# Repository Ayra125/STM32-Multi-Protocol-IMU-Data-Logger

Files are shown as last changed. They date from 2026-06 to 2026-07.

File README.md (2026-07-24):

# STM32 Multi-Protocol IMU Data Logger

A custom two-layer STM32F446 PCB and firmware architecture for a multi-protocol IMU data logger —
designed to sample an IMU over I²C, log to SPI flash, drive an OLED, and stream telemetry through a
USB-UART bridge. The board was designed from first principles in Altium and taken through schematic,
layout, DRC, and a full manufacturing (Gerber/BOM/CPL) review.

> **Project status — hardware-design & firmware-architecture prototype.** Revision 1 of the PCB is
> design-complete and manufacturing-ready (ERC/DRC passed; Gerber/drill/BOM/CPL generated and reviewed
> for JLCPCB), and the three peripheral drivers plus the end-to-end data-logging loop are written. The
> firmware **builds clean** (zero warnings) and has been **flashed to a Nucleo-F446RE**, where the main
> loop, USART2 telemetry (115200), and error-handling paths are confirmed running. However, the custom
> board has **not** been fabricated or electrically tested, and the sensor/OLED/flash **success paths
> have not yet been validated with the peripherals wired up**. Treat this as a PCB + firmware-
> architecture prototype, not a fully validated data logger — see
> [Known limitations](#known-limitations--revision-2).

The point of the project is to demonstrate the electrical-level work a breakout module hides —
component selection, bus loading, pull-up sizing, decoupling, power, PCB layout, and design-rule
verification — not just firmware running on a dev board.

## Board preview

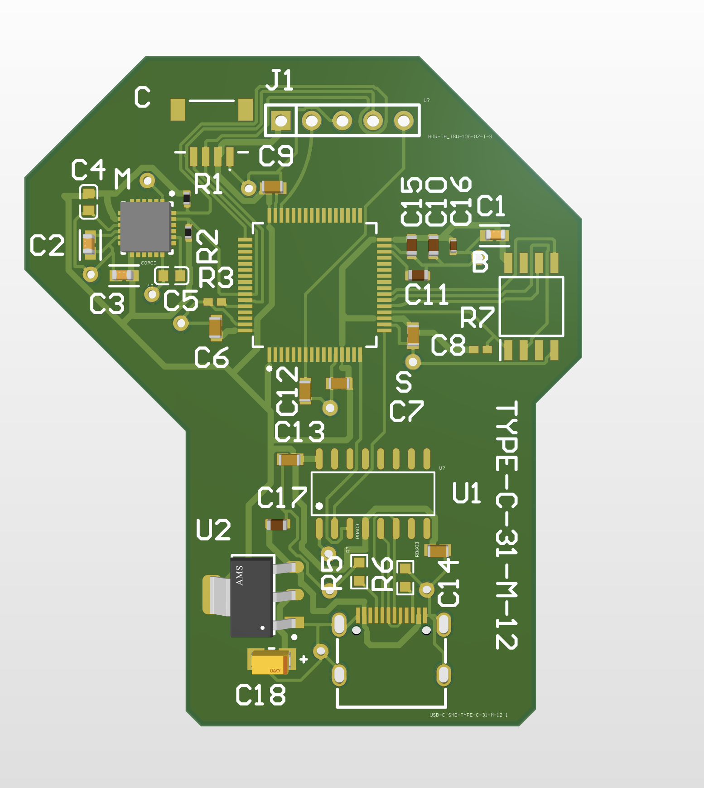
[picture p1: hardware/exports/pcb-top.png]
Altium 3D render of the Revision 1 board, top side


*Altium 3D render — top side, Revision 1.*

<!-- TODO after Altium export: hardware/exports/pcb-bottom.png + a clean schematic-only PDF -->
<!-- TODO after fabrication: assembled-board photo + a 20–40s demo GIF (IMU motion -> live OLED
     values -> UART telemetry in a terminal -> logged samples read back from flash) -->

## System architecture

```mermaid
graph LR
    USBC["USB-C<br/>(TYPE-C-31-M-12)"]
    LDO["AMS1117-3.3<br/>LDO"]
    CH340C["CH340C<br/>USB-UART bridge"]
    MCU["STM32F446RET6<br/>(LQFP-64)"]
    MPU["MPU-6050<br/>IMU"]
    OLED["SSD1306<br/>OLED (external)"]
    FLASH["W25Q128<br/>SPI flash"]

    USBC -->|"5 V"| LDO
    LDO -->|"3.3 V"| MCU
    USBC <-->|"USB D+/D-"| CH340C
    CH340C <-->|"USART2 (PA2/PA3)"| MCU
    MCU <-->|"I2C1 (PB6/PB7)"| MPU
    MCU <-->|"I2C1 (shared bus)"| OLED
    MCU <-->|"SPI1 (PA4-PA7)"| FLASH
```

- **I2C1** — the MCU reads the MPU-6050 IMU and drives the SSD1306 OLED: two devices sharing one bus
  (bus loading, shared pull-ups, address arbitration).
- **SPI1** — the MCU logs data to the W25Q128 flash: a different bus with a different electrical
  model (push-pull vs. I²C's open-drain).
- **USART2** — debug/telemetry to a host terminal, carried over USB-C via the CH340C bridge. USB is
  transport only (like an FTDI cable); USART2 stays the demonstrated protocol.

## What I personally designed

**Original design work (mine):**
- Full schematic (STM32 support/reset/boot, power tree, USB-C + CH340C, three-peripheral bus design).
- PCB layout, routing, ground pour, and design-rule setup for JLCPCB 2-layer manufacturing.
- All three peripheral drivers (`mpu6050`, `ssd1306`, `w25q128`) and the application data-logging loop in C.
- The engineering calculations below (pull-up sizing, bus capacitance, decoupling, LDO dissipation).

**CAD models — hand-built:** the USB-C receptacle symbol + footprint were drawn by hand, because no
usable vendor model existed for that part.

**CAD models — imported and then validated/adapted:** the CH340C and some capacitor models were
pulled in via EasyEDA/LCSC and then checked and adjusted for this design (pin mapping, land pattern,
parameters) rather than authored from scratch.

**Generated / vendor-provided (not my work):** STM32 HAL and CMSIS, and the CubeMX-generated
peripheral init / MSP boilerplate under `firmware/Core/` and `firmware/Drivers/`.

## Hardware specifications

| Function | Part | Bus / Role |
|---|---|---|
| MCU | STM32F446RET6 (LQFP-64) | — |
| IMU | MPU-6050 (QFN-24) | **I2C1** |
| OLED display | SSD1306 (external module, not on PCBA) | **I2C1** (shared bus) |
| Flash | W25Q128 (SOIC-8) | **SPI1** |
| USB-UART bridge | CH340C (SOP-16) | **USART2** telemetry to host |
| Connector | Single USB-C (TYPE-C-31-M-12) | Power-in + UART transport |
| Regulator | AMS1117-3.3 (SOT-223) | 5 V → 3.3 V |

- **Board:** 2-layer FR-4, 1.6 mm, 1 oz copper, ENIG finish, ≈ 46.1 mm × 55.37 mm.
- **Manufacturing:** JLCPCB SMT assembly (parts chosen JLCPCB-Basic where possible). The reviewed
  Revision 1 release lives in [`hardware/manufacturing/rev1/`](hardware/manufacturing/rev1).
- Firmware was developed on a Nucleo-F446RE; the custom board moves to the bare STM32F446RET6.

## Firmware architecture & data flow

Bare-metal STM32 HAL, no RTOS. Each peripheral is an independent driver module:

| Module | File | Bus |
|---|---|---|
| MPU-6050 IMU | `firmware/Peripherals/i2c/mpu6050.{c,h}` | I2C1 |
| SSD1306 OLED | `firmware/Peripherals/i2c/ssd1306.{c,h}` | I2C1 |
| W25Q128 flash | `firmware/Peripherals/spi/w25q128.{c,h}` | SPI1 |

`main()` configures the clock and peripherals, initializes each device (reporting failures over
UART), then enters its loop.

**End-to-end data path:** each loop pass reads the MPU-6050 accelerometer and gyroscope over I²C →
renders both on the SSD1306 OLED → streams the same values as text over UART → appends a 12-byte record
(six `int16_t` axes) to the W25Q128 flash, with 16-byte alignment (so no page-boundary straddle) and
automatic sector-erase wraparound → paced at 10 Hz via `HAL_Delay`. Every peripheral call checks its
HAL status and reports failures over UART.

The firmware builds clean and runs on a Nucleo-F446RE: with no peripherals attached, the board streams
the expected `ReadAccel fail / ReadGyro fail / Clear failed` sequence over USART2 at 115200, confirming
the loop, UART telemetry, and fault-reporting work on hardware. The remaining bring-up is validating
the **success** paths with the three peripherals wired up (see
[Known limitations](#known-limitations--revision-2)).

## Engineering calculations & trade-offs

A few of the decisions reasoned from datasheets/first principles rather than copied from a reference
design (full derivations in the design notes):

- **I²C pull-ups (R1/R2):** from UM10204, `Rp(max) = tr / (0.8473 · Cb)` and
  `Rp(min) = (VDD − VOL) / IOL` give a valid window of **≈ 967 Ω – 17.6 kΩ**. Chose **2.2 kΩ** — well
  inside the window and available as a JLCPCB **Basic** 0402 part (`C25879`).
- **Bus capacitance:** device pin capacitance (~10 pF each) + trace capacitance (~0.11 pF, negligible)
  ≈ 20 pF, only ~5 % of the 400 pF Fast-mode budget — ample rise-time margin on the shared bus.
- **Decoupling:** values taken directly from each datasheet (STM32 per-pin 100 nF + 4.7 µF bulk +
  VCAP; MPU-6050 REGOUT/VDD/VLOGIC/CPOUT; flash 100 nF).
- **Power:** AMS1117-3.3 LDO with a 4.7 µF ceramic input cap (C17) and a 22 µF tantalum output cap
  (C18, matching the datasheet's output-stability recommendation); worst-case ≈ 0.5 W on SOT-223 —
  fine with modest copper pour, no heatsink.
- **USB transport:** chose a discrete **CH340C** USB-UART bridge over native STM32 USB, so USART2
  stays the demonstrated protocol (no USB device stack) and the HSE crystal becomes optional. A
  single **USB-C** connector handles both power and UART; the earlier dual-port VBUS ORing scheme was
  dropped as unnecessary.

## Build & reproduce

**Firmware:**
```bash
cd firmware
make            # builds with arm-none-eabi-gcc; outputs under build/ (gitignored)
```

**Hardware:** open `hardware/altium/IMU sensor node hardware.PrjPcb` in Altium Designer. Manufacturing
outputs are regenerated from the project's OutJob (`IMU sensor node hardware.OutJob`); the reviewed
Revision 1 set is committed under `hardware/manufacturing/rev1/`.

## Verification results

- **Design verification (done):** schematic ERC clean; PCB DRC clean (with ShortCircuit and
  Board-Outline-clearance rules enabled); schematic-to-PCB comparison reviewed; JLCPCB matched all
  assembled BOM line items and previewed placement.
- **Firmware bring-up (partial, done on a Nucleo-F446RE):** builds clean (zero warnings); flashed over
  ST-LINK/SWD; the application loop, USART2 telemetry at 115200, and error-handling paths are confirmed
  running (with no peripherals attached, the board streams the expected `ReadAccel fail / ReadGyro fail
  / Clear failed` sequence). Success paths (live IMU/OLED/flash) still pending the wired-up modules.
- **Hardware verification (pending):** power-rail, short-circuit, SWD, USB-UART, I²C, SPI, and
  firmware bring-up will be recorded after fabrication — planned under `docs/verification/` (logic-
  analyzer captures, measured I²C rise time vs. the calculated limit, SPI mode/clock, flash
  read/write/erase, power-rail measurements).

## Known limitations & Revision 2

**Hardware:** not yet fabricated, assembled, or electrically tested. The MPU-6050 is obsolete
(retained for Rev 1 because it's still JLCPCB-stocked) — migrate to a current IMU in Rev 2. The
1×5 SWD header (J1) is excluded from PCBA and hand-soldered. Silkscreen designators are still being
normalized (some unconventional refs — `S`/`M`/`B`/`C` — and `U?` placeholders remain, visible in the
top render) and will be cleaned up before fabrication.

**Firmware (open items before it can be called validated):**
- The application loop builds clean and runs on a Nucleo-F446RE (loop, UART telemetry, and error paths
  confirmed). The **success paths are not yet validated** — no peripherals were attached, so live IMU
  reads, OLED rendering, and flash read/write/erase remain to be exercised with the modules wired up.
- `SystemClock_Config()` currently runs the core from the **16 MHz HSI with no PLL**, not the 180 MHz
  the dev log mentions; the PLL config needs to be added.
- **PA4 chip-select conflict:** the SPI1 MSP configures PA4 as `GPIO_AF5_SPI1` (hardware NSS) after
  `MX_GPIO_Init` set it as a GPIO output, so the flash driver's software CS (`HAL_GPIO_WritePin`)
  can't drive it. PA4 needs to stay a plain GPIO output.
- Several flash SPI transfers don't check `HAL_SPI_Transmit/Receive` return codes.
- `W25Q128_Init` verifies only the JEDEC manufacturer byte — check the full ID.
- The CubeMX `.ioc` is not committed (currently gitignored), so the pin/clock config isn't reproducible.

**Documentation & exports:**
- [`hardware/exports/schematic.pdf`](hardware/exports/schematic.pdf) is a **draft/reference** export,
  not a polished package: page 2 is clipped, title blocks are incomplete, and the PCB page is small
  with excess whitespace. A clean schematic-only PDF export is pending (requires Altium).
- The top-side 3D render (`pcb-top.png`) is included; the **bottom-side** render is not yet exported.
- The `hardware/altium/*.OutJob` uses absolute Windows paths; its source/output paths must be
  reassigned in Altium after cloning (see [`hardware/README.md`](hardware/README.md)).

## Repository structure

```
firmware/
├── Core/             # CubeMX-generated HAL core (main, clock, MSP, startup)
├── Drivers/          # STM32 HAL & CMSIS
├── Peripherals/      # Authored drivers — i2c/ (MPU6050, SSD1306), spi/ (W25Q128)
└── Makefile
hardware/
├── altium/           # Altium source design (.PrjPcb, .SchDoc, .PcbDoc, .BomDoc, .OutJob, libraries/)
├── manufacturing/
│   └── rev1/         # Reviewed release: gerbers.zip, bom.xlsx, cpl.xlsx
└── exports/          # pcb-top.png (3D render), schematic.pdf (draft); bottom render TODO
docs/
├── datasheets/       # MPU6050, SSD1306, W25Q128, STM32F446RE
└── wiring/
```

## License

MIT — see [`LICENSE`](LICENSE). Covers the authored firmware drivers and hardware design.
STM32 HAL/CMSIS retain their original STMicroelectronics licenses.

## Changelog

### 2026-07-24 — Firmware bring-up on Nucleo-F446RE

First on-hardware run. Built the firmware clean (zero warnings, ~15.8 KB) with the GNU ARM toolchain
and flashed it to a Nucleo-F446RE over ST-LINK/SWD. With no peripherals attached, the board streams the
expected `ReadAccel fail / ReadGyro fail / Clear failed` sequence over USART2 at 115200 — confirming the
main loop, UART telemetry, and error-handling paths run correctly on hardware. Success paths (live IMU,
OLED, flash) remain to be validated with the breakout modules wired up.

### 2026-07-23 — Firmware: end-to-end data-logging loop

Implemented the main application loop in `main.c`: reads MPU-6050 accel + gyro over I²C, renders both
lines on the SSD1306 (added an `SSD1306_SetCursor` helper for multi-line output), streams the values
over UART, and logs a 12-byte record per sample to the W25Q128 — with 16-byte page alignment and
automatic sector-erase wraparound (with the erase status checked before the write pointer resets).
Every peripheral call is status-checked with UART fault reporting; loop paced at 10 Hz. Written and
reviewed in source; **not yet compiled or hardware-tested**.

### 2026-07-21 — Revision 1 manufacturing-ready

- Altium design finalized: ERC/DRC clean, Gerbers (corrected key-shaped outline), drill, BOM, and CPL
  generated and reviewed in JLCPCB; placement previewed. Board ≈ 46.1 × 55.37 mm, 2-layer, ENIG.
- MPU-6050 exposed-pad footprint corrected (no paste/routing/vias beneath the die pad; continuous
  bottom GND plane kept for shielding).
- Power/UART path finalized: single USB-C, CH340C USB-UART bridge on USART2 (3.3 V, no level shift),
  AMS1117-3.3 LDO. HSE crystal made optional.
- I²C pull-ups set to 2.2 kΩ (`C25879`, JLCPCB Basic).
- JLCPCB quote $185.35; order deferred for budget. J1 excluded from PCBA (hand-soldered).
- Repository: imported the Altium project and published the reviewed Rev 1 manufacturing release
  under `hardware/`.

### 2026-07-08 — Pre-Altium design phase

Worked through every schematic decision from first principles before entering Altium — I²C trace
width, bus capacitance vs. the 400 pF ceiling, pull-up sizing, W25Q128 SPI mode, and the STM32
crystal/reset/boot/decoupling support circuitry. (The 1.5 kΩ pull-up chosen here was later revised to
2.2 kΩ for JLCPCB Basic-tier sourcing.)

### 2026-04-30 – 2026-06-30 — Firmware drivers

MPU-6050 (I²C), SSD1306 (I²C), and W25Q128 (SPI) drivers written and iterated on the Nucleo-F446RE;
Makefile build system; peripheral init and error reporting in `main.c`. See `DEVLOG.md` for the
detailed per-commit history.

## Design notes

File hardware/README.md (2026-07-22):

# Hardware — STM32 Multi-Protocol IMU Data Logger

Custom two-layer PCB for the STM32F446-based IMU data logger, designed in **Altium Designer** and
prepared for **JLCPCB** SMT assembly. See the [root README](../README.md) for the system overview,
schematic reasoning, and engineering calculations.

> **Revision 1:** design complete — ERC/DRC clean, Gerber/drill/BOM/CPL generated and reviewed for
> manufacturing. **Not yet fabricated, assembled, or electrically tested.**

## Layout

```
hardware/
├── altium/                 # Source design (open this in Altium)
│   ├── IMU sensor node hardware.PrjPcb      # project
│   ├── IMU_sensor_node_hardware.PcbDoc      # board (live PCB)
│   ├── Periferals.SchDoc / Support.SchDoc   # schematic sheets
│   ├── IMU sensor node hardware.BomDoc      # BOM document
│   ├── IMU sensor node hardware.OutJob      # output job (absolute paths — see caveat below)
│   └── libraries/          # libraries/schematic/ holds ONE SchLib; see "CAD models" below
├── manufacturing/
│   └── rev1/               # Reviewed release (what was checked against JLCPCB)
│       ├── gerbers.zip     # corrected key-shaped outline, copper/mask/paste/silk + NC drill
│       ├── bom.xlsx        # JLCPCB BOM (J1 excluded from PCBA)
│       ├── cpl.xlsx        # JLCPCB component placement list (J1 excluded)
│       └── SOURCING.md     # R1/R2 substitution + ordering notes
└── exports/
    ├── pcb-top.png                # Altium 3D render, top side (Rev 1)
    ├── schematic.pdf              # DRAFT/reference printout (not a clean final export)
    └── cpl-table-screenshot.png   # screenshot of the CPL spreadsheet (not a PCB image)
```

Altium-generated intermediates (`History/`, `__Previews/`, `Project Outputs/`, CAMtastic files) are
gitignored — the source design plus the reviewed `manufacturing/rev1/` release are the tracked
artifacts.

## Custom CAD models & library reproducibility

`libraries/schematic/` currently contains a **single** SchLib (the 2.2 nF capacitor symbol), and no
footprint libraries (`.PcbLib`) are committed. The other custom parts are **not** all present as
standalone library files:

- The **USB-C receptacle** symbol/footprint was hand-built; the **CH340C** and some capacitor models
  were imported via EasyEDA/LCSC and validated/adapted.
- Most of these live **embedded inside** `Support.SchDoc` / `Periferals.SchDoc` / the `.PcbDoc`, or
  originated from an **Altium 365 workspace server**, rather than as files in `libraries/`.

**Reproducibility limitation:** the board opens and renders from the committed source because the
models are embedded in the documents, but the project **cannot be fully library-updated / re-linked
from a clean machine** without the original Altium workspace (or rebuilding those library items).
Treat `libraries/` as partial, not the complete part library.

## Board specifications

- 2-layer FR-4, 1.6 mm, 1 oz outer copper, ENIG finish, green mask / white silk.
- ≈ 46.1 mm × 55.37 mm, tented vias, standard ±0.2 mm outline tolerance.
- JLCPCB Economic PCBA, top-side assembly. Parts chosen JLCPCB-**Basic** where possible; 4 Extended
  parts (STM32, MPU-6050, USB-C, CH340C).

## Reproducing the manufacturing outputs

1. Open `altium/IMU sensor node hardware.PrjPcb` in Altium Designer.
2. Run the OutJob (`IMU sensor node hardware.OutJob`) to regenerate Gerbers, NC drill, BOM, and CPL.
3. The reviewed Revision 1 set is committed under `manufacturing/rev1/` for reference.

> **OutJob portability caveat:** `IMU sensor node hardware.OutJob` hard-codes absolute Windows paths
> (`C:\Users\Public\Documents\Altium\IMU sensor node hardware\…`) for its source PCB and PDF output
> targets. These were left as-is deliberately — Altium's portable-path encoding depends on per-output
> "relative to project" flags that can't be set safely by editing the file directly. **After cloning
> on a different machine, reassign the OutJob's source and output paths inside Altium** before
> regenerating, and verify the output targets.

## Assembly notes

- **R1/R2 (I²C pull-ups):** the BOM's manufacturer part number and the assembled LCSC part differ by
  design — see [`manufacturing/rev1/SOURCING.md`](manufacturing/rev1/SOURCING.md) for the substitution
  and why it's compatible.
- **J1 (SWD header):** intentionally excluded from the JLCPCB BOM/CPL (through-hole part, avoids
  assembly cost). The footprint is on the board — hand-solder a 1×5, 2.54 mm vertical male header.
- **MPU-6050:** obsolete but still JLCPCB-stocked; retained for Rev 1, to be replaced with a current
  IMU in Rev 2. Its exposed pad is **not** soldered and has no vias/routing beneath it; a continuous
  bottom GND plane under the package provides shielding.
- Recheck live JLCPCB stock, Basic/Extended tiers, and pricing before ordering — availability drifts.

## Pending (Revision 1)

Fabrication, assembly, and hardware bring-up (power-rail, short-circuit, SWD, USB-UART, I²C, SPI, and
firmware validation) are the remaining steps. Results will be recorded under `docs/verification/`.

Export work still pending in Altium:
- The **bottom-side** board render (`pcb-bottom.png`). The top-side 3D render (`exports/pcb-top.png`)
  is included.
- A **clean schematic-only PDF**. The current `exports/schematic.pdf` is a draft/reference only —
  page 2 is clipped, title blocks are incomplete, and the PCB page is small with excess whitespace.

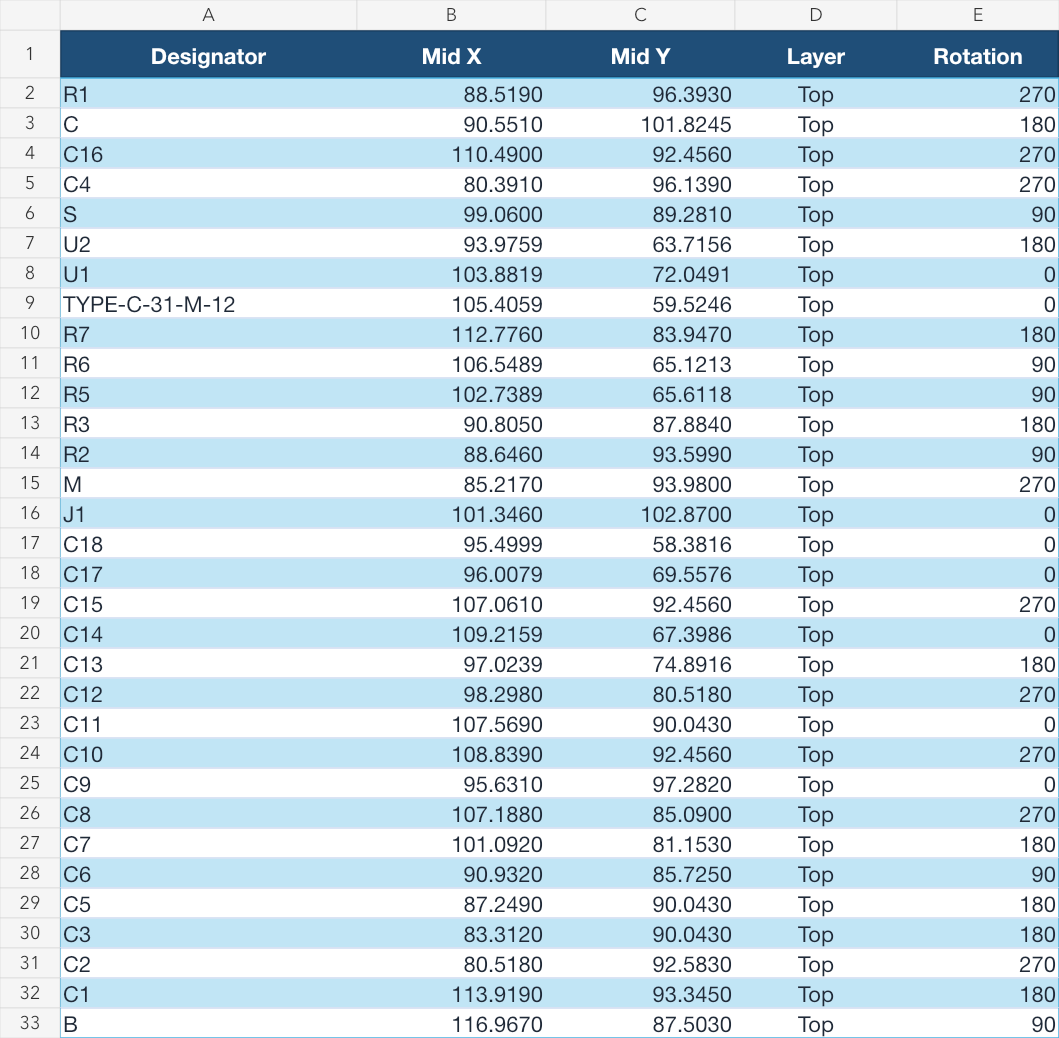
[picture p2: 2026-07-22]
hardware/exports/cpl-table-screenshot.png

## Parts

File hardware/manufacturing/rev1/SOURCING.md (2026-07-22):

# Revision 1 — sourcing notes

Notes on the released BOM (`bom.xlsx`) / CPL (`cpl.xlsx`) for JLCPCB assembly. JLCPCB places parts
by the **LCSC part number** (the `C#####` in the `LCSC Part #` column), so that column — not the
`Manufacturer Part Number` column — determines the part actually assembled.

## Intentional substitution — R1 / R2 (I²C pull-ups)

| BOM field | Value |
|---|---|
| Designators | R1, R2 |
| `Comment` / `Manufacturer Part Number 1` | Resistor 2.2 kΩ ±5% 0402 63 mW / **CR0402-JW-222GLF** (Bourns) |
| `LCSC Part #` (what gets placed) | **C25879** = `0402WGF2201TCE` (UNI-ROYAL), 2.2 kΩ **±1%** 0402, 62.5 mW |

**What this means:** the `Manufacturer Part Number` column still carries the original Altium library
entry (Bourns `CR0402-JW-222GLF`, ±5%), while the linked LCSC part `C25879` is the deliberately
chosen UNI-ROYAL `0402WGF2201TCE` (±1%). The assembled resistor is therefore the ±1% UNI-ROYAL part.

**Why the substitute is compatible:**
- Same resistance (2.2 kΩ) and same package (0402) — mechanically and electrically drop-in.
- Tighter tolerance (±1% vs. ±5%) — strictly better for the I²C rise-time budget, never worse.
- Well inside the derived valid pull-up window of ≈ 967 Ω – 17.6 kΩ (see the root README's
  engineering-calculations section).
- `C25879` is a JLCPCB **Basic** part (no per-part fee), which is why it was selected over the
  original MPN.

**Do not "fix" the MPN column by editing `bom.xlsx`.** JLCPCB keys off the LCSC `C25879`; changing the
MPN text is unnecessary and risks corrupting the upload workbook. This note is the record of intent.

## Before ordering

Re-check live JLCPCB stock, the Basic/Extended tier, and pricing for every line — availability and
tiers drift over time. The MPU-6050 (`C24112`) in particular is obsolete but currently JLCPCB-stocked;
confirm it is still assemblable at order time.

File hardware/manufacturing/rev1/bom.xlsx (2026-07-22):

Comment | Designator | Quantity | Manufacturer Part Number 1 | Footprint | LCSC Part #
W25Q128JVSIQ | B | 1 | W25Q128JVSIQ | SOIC127P790X216-8N | C97521
TYPE-C-31-M-12 | TYPE-C-31-M-12 | 1 | TYPE-C-31-M-12 | PCBComponent_1 | C165948
TAJA226M010RNJ | C18 | 1 | TAJA226M010RNJ | FP-TAJA-MFG | C7183
STM32F446RET6 | S | 1 | STM32F446RET6 | FP-LQFP64-5W-MFG | C69336
SM04B-SRSS-TB(LF)(SN) | C | 1 | SM04B-SRSS-TB(LF)(SN) | SM04BSRSSTBLFSN | C160404
Resistor 2.2kΩ ±5% 0402 63mW | R1, R2 | 2 | CR0402-JW-222GLF | RESC0402(1005)_L | C25879
MPU6050 | M | 1 | MPU-6050 | INSE-QFN-24_V | C24112
CH340C | U1 | 1 | CH340C | PCBComponent_1 | C84681
CC0603KRX7R9BB104 | C1, C2, C3 | 3 | CC0603KRX7R9BB104 | FP-CC0603-DA-IPC_B | C14663
Capacitor 100 nF +/-10% 50 V 0603 | C6, C7, C8, C9, C12, C13, C14 | 7 | 06035C104KAT2A | CAPC1608X90X40NL10T20 | C88476
Capacitor 10nF +/-20% 50V 0402 | C16 | 1 | GRM155R71H103KA88D | CAPC0402(1005)60_L | C77019
Capacitor 4.7µF +/-20% 10V 0603 | C11, C15, C17 | 3 | CC0603KRX5R6BB475 | CAPC0603(1608)100_L | C109456
Capacitor 1µF +/-40% 50V 0603 | C10 | 1 | CL10A105KB8NNNC | CAPC0603(1608)100_L | C15849
AMS1117-3.3 | U2 | 1 | AMS1117-3.3 | FP-AMS1117-IPC_A | C6186
0603WAF5101T5E | R5, R6 | 2 | 0603WAF5101T5E | PCBComponent_1 | C23186
0603B222K500NT | C5 | 1 | 0603B222K500NT | PCBComponent_1 | C1604
0603B103K500NT | C4 | 1 | 0603B103K500NT | PCBComponent_1 | C57112
0402WGF1002TCE | R3, R7 | 2 | 0402WGF1002TCE | RESC1005X40N | C25744

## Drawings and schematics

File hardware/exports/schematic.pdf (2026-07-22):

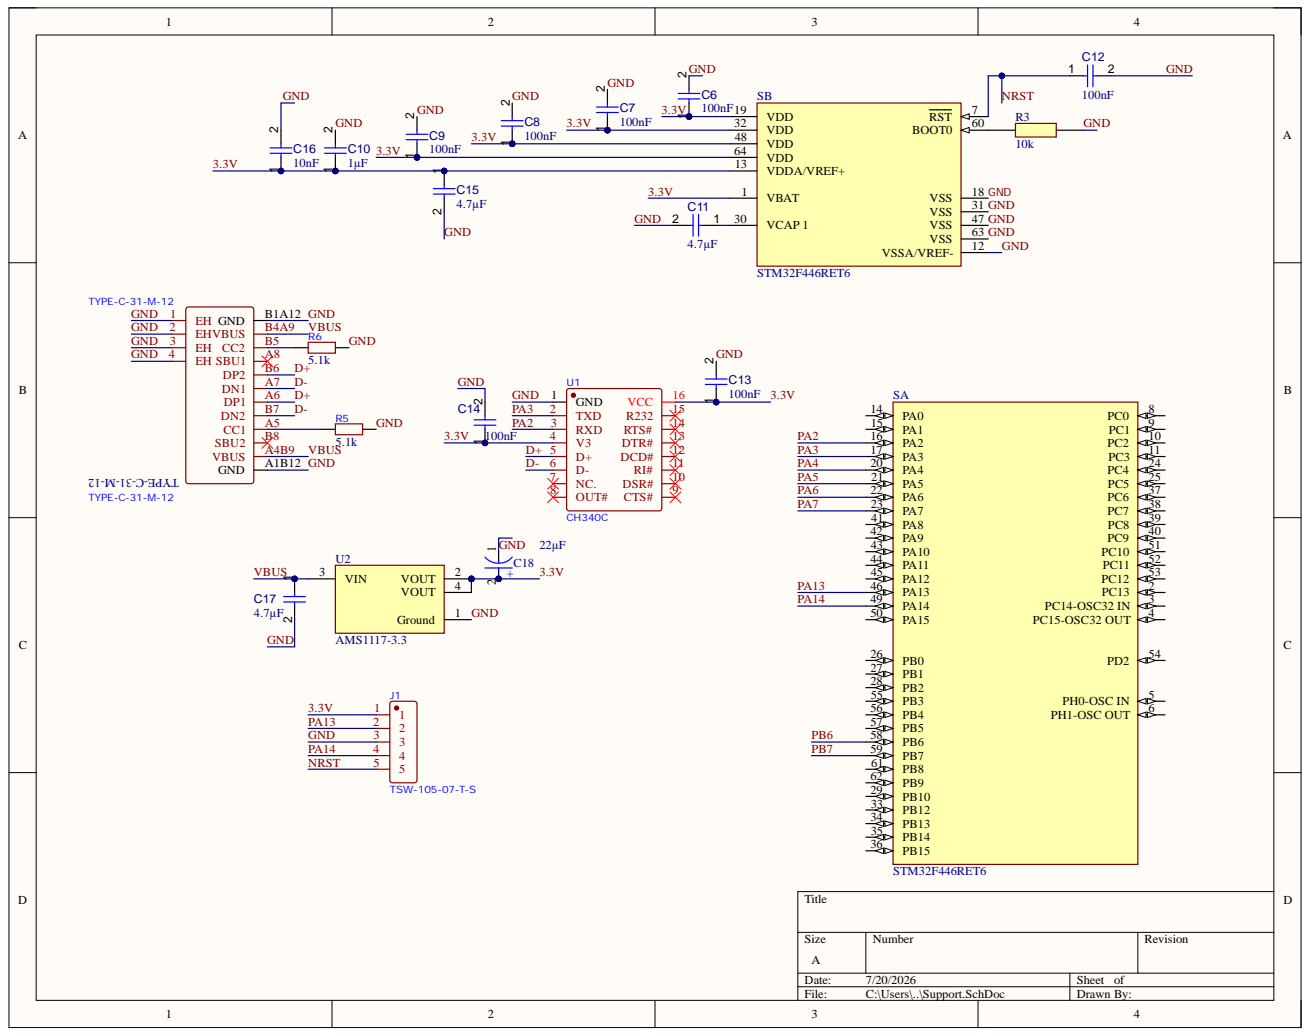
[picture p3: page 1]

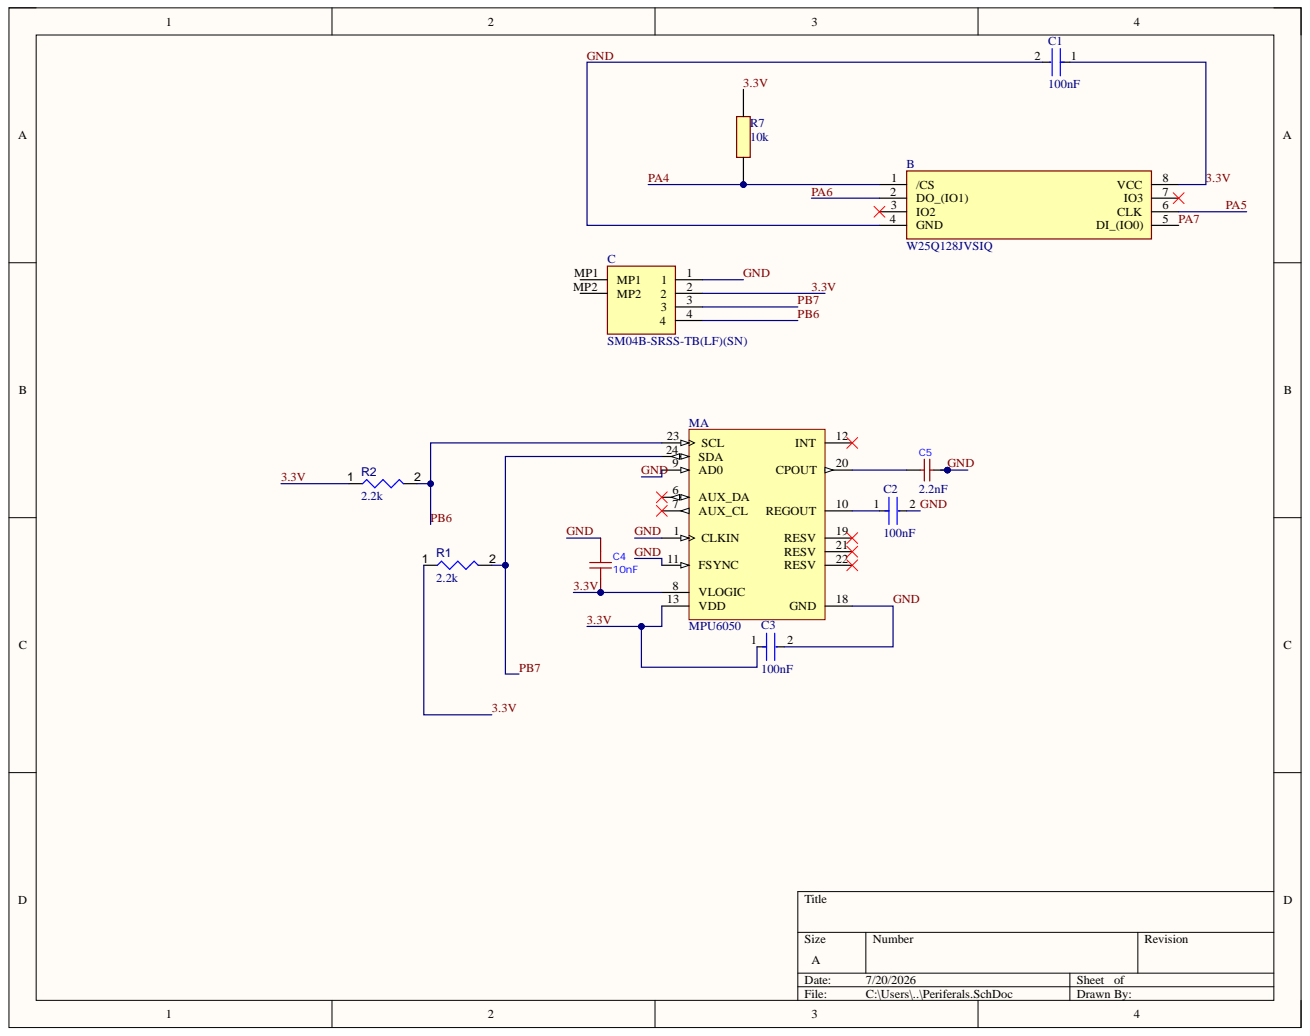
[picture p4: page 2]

SM04B-SRSS-TB(LF)(SN)

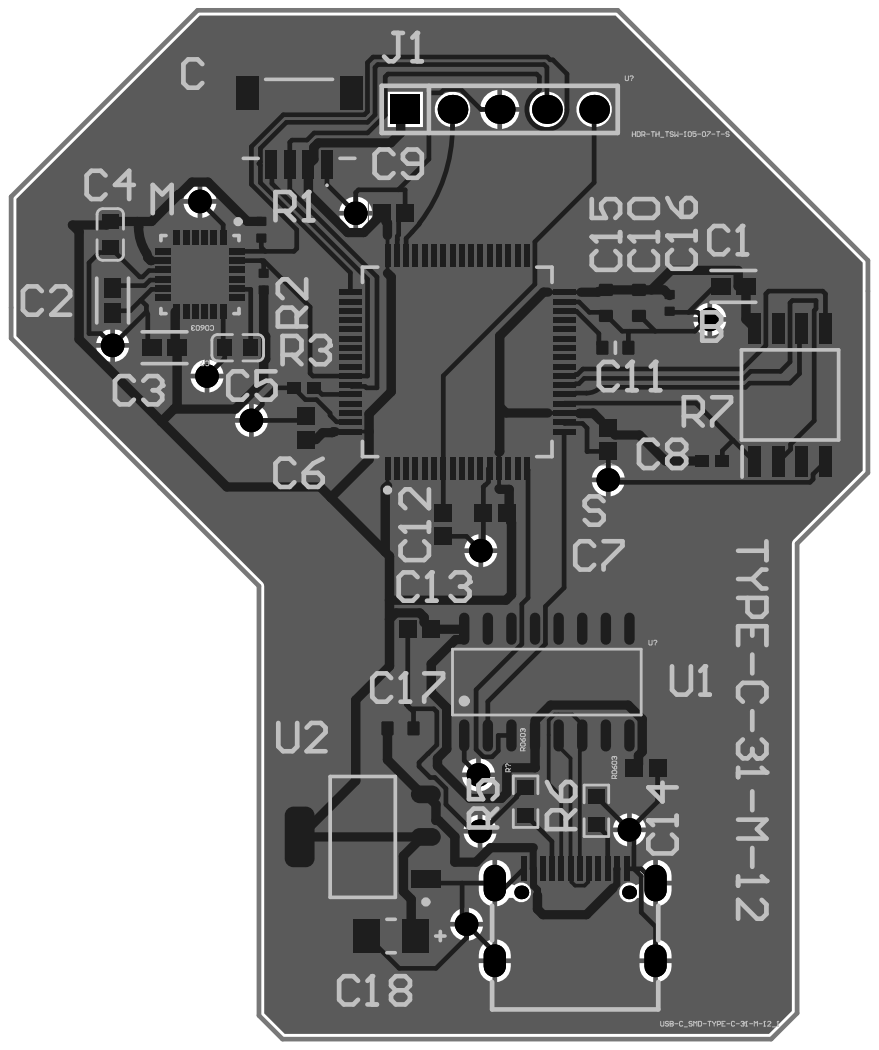
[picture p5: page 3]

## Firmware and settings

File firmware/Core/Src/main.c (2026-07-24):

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
/* Includes ------------------------------------------------------------------*/
#include "main.h"

/* USER CODE BEGIN Includes */
#include "ssd1306.h"
#include "w25q128.h"
#include "stm32f4xx_hal.h"
#include "mpu6050.h"
#include <string.h>
#include <stdio.h>

/* USER CODE END Includes */

I2C_HandleTypeDef hi2c1;

SPI_HandleTypeDef hspi1;

UART_HandleTypeDef huart2;

void SystemClock_Config(void);
static void MX_GPIO_Init(void);
static void MX_I2C1_Init(void);
static void MX_SPI1_Init(void);
static void MX_USART2_UART_Init(void);
/* Led set up*/


/**
  * @brief  The application entry point.
  * @retval int
  */
int main(void)
{

  /* MCU Configuration--------------------------------------------------------*/

  /* Reset of all peripherals, Initializes the Flash interface and the Systick. */
  HAL_Init();

  /* Configure the system clock */
  SystemClock_Config();

  /* Initialize all configured peripherals */
  MX_GPIO_Init();
  MX_I2C1_Init();
  MX_SPI1_Init();
  MX_USART2_UART_Init();
  /* USER CODE BEGIN 2 */
uint8_t init_ok = 1;
if (MPU6050_Init(&hi2c1) != HAL_OK)
{
    HAL_UART_Transmit(&huart2, (uint8_t*)"MPU6050 Init Failed\r\n", strlen("MPU6050 Init Failed\r\n"), 100);
    init_ok = 0;
}
if (W25Q128_Init(&hspi1) != HAL_OK)
{
    HAL_UART_Transmit(&huart2, (uint8_t*)"W25Q128 Init Failed\r\n", strlen("W25Q128 Init Failed\r\n"), 100);
    init_ok = 0;
}
if (SSD1306_Init(&hi2c1) != HAL_OK)
{
    HAL_UART_Transmit(&huart2, (uint8_t*)"SSD1306 Init Failed\r\n", strlen("SSD1306 Init Failed\r\n"), 100);
    init_ok = 0;
}
if(W25Q128_EraseSector(&hspi1,0x000000) != HAL_OK){

    HAL_UART_Transmit(&huart2, (uint8_t*)"EraseSector failed\r\n", strlen("EraseSector failed\r\n"), 100);
    init_ok=0;
  }
if (init_ok)
{
    HAL_UART_Transmit(&huart2, (uint8_t*)"All peripherals initialized\r\n", strlen("All peripherals initialized\r\n"), 100);
}
  /* USER CODE END 2 */
 
  /* Infinite loop */
  /* USER CODE BEGIN WHILE */
  int16_t gx, gy, gz, x, y, z;
  char bufferA[60];
  char bufferG[60];
  uint32_t nextWriteLog=0;
  while (1)
  {
    if(nextWriteLog>=4096){
      HAL_StatusTypeDef EraseSectorA = W25Q128_EraseSector(&hspi1, 0x000000);
      if(EraseSectorA != HAL_OK) HAL_UART_Transmit(&huart2, (uint8_t*)"EraseSectorA failed\r\n", strlen("EraseSectorA failed\r\n"), 100);
      if(EraseSectorA == HAL_OK)nextWriteLog = 0;
    }
    HAL_StatusTypeDef accelStatus = MPU6050_ReadAccel(&hi2c1, &x, &y, &z);
    HAL_StatusTypeDef gyroStatus = MPU6050_ReadGYRO(&hi2c1,&gx, &gy, &gz);
    HAL_StatusTypeDef clear = SSD1306_Clear(&hi2c1);
if (accelStatus == HAL_OK && clear == HAL_OK) {
    snprintf(bufferA,sizeof(bufferA),"MPU6050 Read Accel: Ax:%d Ay:%d, Az:%d",x,y,z);
    HAL_StatusTypeDef SetCursorA = SSD1306_SetCursor(&hi2c1,0,0);
    HAL_StatusTypeDef WriteStringA = SSD1306_WriteString(&hi2c1,bufferA);
    if(SetCursorA == HAL_OK && WriteStringA == HAL_OK){
      HAL_UART_Transmit(&huart2,(uint8_t*)bufferA,strlen(bufferA),100);
    }
  if(SetCursorA != HAL_OK) HAL_UART_Transmit(&huart2, (uint8_t*)"SetCursorA failed\r\n", strlen("SetCursorA failed\r\n"), 100);
  if(WriteStringA != HAL_OK) HAL_UART_Transmit(&huart2, (uint8_t*)"WriteStringA failed\r\n", strlen("WriteStringA failed\r\n"), 100);
} 
if (gyroStatus == HAL_OK && clear == HAL_OK) {
    snprintf(bufferG,sizeof(bufferG),"MPU6050 Read Gyro: Gx:%d Gy:%d, Gz:%d",gx,gy,gz);
     HAL_StatusTypeDef SetCursorG =  SSD1306_SetCursor(&hi2c1,1,0);
     HAL_StatusTypeDef WriteStringG = SSD1306_WriteString(&hi2c1,bufferG);
     if(SetCursorG == HAL_OK && WriteStringG == HAL_OK){
      HAL_UART_Transmit(&huart2,(uint8_t*)bufferG,strlen(bufferG),100);
     }
  if(SetCursorG != HAL_OK) HAL_UART_Transmit(&huart2, (uint8_t*)"SetCursorG failed\r\n", strlen("SetCursorG failed\r\n"), 100);
  if(WriteStringG != HAL_OK) HAL_UART_Transmit(&huart2, (uint8_t*)"WriteStringG failed\r\n", strlen("WriteStringG failed\r\n"), 100);
} 
  if(accelStatus != HAL_OK)HAL_UART_Transmit(&huart2, (uint8_t*)"ReadAccel fail\r\n", strlen("ReadAccel fail\r\n"), 100);
  if(gyroStatus != HAL_OK)HAL_UART_Transmit(&huart2, (uint8_t*)"ReadGyro fail\r\n", strlen("ReadGyro fail\r\n"), 100);
  if (clear != HAL_OK) HAL_UART_Transmit(&huart2, (uint8_t*)"Clear failed\r\n", strlen("Clear failed\r\n"), 100);
   if(accelStatus == HAL_OK && gyroStatus == HAL_OK){
    int16_t record[6];
    record[0]=x;
    record[1]=y;
    record[2]=z;
    record[3]=gx;
    record[4]=gy;
    record[5]=gz;
     HAL_StatusTypeDef W25Q128_WriteS =  W25Q128_Write(&hspi1,nextWriteLog,(uint8_t*)record,12);
    if(W25Q128_WriteS != HAL_OK) HAL_UART_Transmit(&huart2, (uint8_t*)"W25Q128_Write fail\r\n", strlen("W25Q128_Write fail\r\n"), 100);
    else if(W25Q128_WriteS == HAL_OK) nextWriteLog += 16;
   } 
   HAL_Delay(100);
  }
 
  /* USER CODE END 3 */
}

 /*
  * @brief System Clock Configuration
  * @retval None
*/
void SystemClock_Config(void)
{
  RCC_OscInitTypeDef RCC_OscInitStruct = {0};
  RCC_ClkInitTypeDef RCC_ClkInitStruct = {0};

  /** Configure the main internal regulator output voltage
  */
  __HAL_RCC_PWR_CLK_ENABLE();
  __HAL_PWR_VOLTAGESCALING_CONFIG(PWR_REGULATOR_VOLTAGE_SCALE3);

  /** Initializes the RCC Oscillators according to the specified parameters
  * in the RCC_OscInitTypeDef structure.
  */
  RCC_OscInitStruct.OscillatorType = RCC_OSCILLATORTYPE_HSI;
  RCC_OscInitStruct.HSIState = RCC_HSI_ON;
  RCC_OscInitStruct.HSICalibrationValue = RCC_HSICALIBRATION_DEFAULT;
  RCC_OscInitStruct.PLL.PLLState = RCC_PLL_NONE;
  if (HAL_RCC_OscConfig(&RCC_OscInitStruct) != HAL_OK)
  {
    Error_Handler();
  }

  /** Initializes the CPU, AHB and APB buses clocks
  */
  RCC_ClkInitStruct.ClockType = RCC_CLOCKTYPE_HCLK|RCC_CLOCKTYPE_SYSCLK
                              |RCC_CLOCKTYPE_PCLK1|RCC_CLOCKTYPE_PCLK2;
  RCC_ClkInitStruct.SYSCLKSource = RCC_SYSCLKSOURCE_HSI;
  RCC_ClkInitStruct.AHBCLKDivider = RCC_SYSCLK_DIV1;
  RCC_ClkInitStruct.APB1CLKDivider = RCC_HCLK_DIV1;
  RCC_ClkInitStruct.APB2CLKDivider = RCC_HCLK_DIV1;

  if (HAL_RCC_ClockConfig(&RCC_ClkInitStruct, FLASH_LATENCY_1) != HAL_OK)
  {
    Error_Handler();
  }
}

/**
  * @brief I2C1 Initialization Function
  * @param None
  * @retval None
  */
static void MX_I2C1_Init(void)
{

  hi2c1.Instance = I2C1;
  hi2c1.Init.ClockSpeed = 100000;
  hi2c1.Init.DutyCycle = I2C_DUTYCYCLE_2;
  hi2c1.Init.OwnAddress1 = 0;
  hi2c1.Init.AddressingMode = I2C_ADDRESSINGMODE_7BIT;
  hi2c1.Init.DualAddressMode = I2C_DUALADDRESS_DISABLE;
  hi2c1.Init.OwnAddress2 = 0;
  hi2c1.Init.GeneralCallMode = I2C_GENERALCALL_DISABLE;
  hi2c1.Init.NoStretchMode = I2C_NOSTRETCH_DISABLE;
  if (HAL_I2C_Init(&hi2c1) != HAL_OK)
  {
    Error_Handler();
  }
}

/**
  * @brief SPI1 Initialization Function
  * @param None
  * @retval None
  */
static void MX_SPI1_Init(void)
{

  /* SPI1 parameter configuration*/
  hspi1.Instance = SPI1;
  hspi1.Init.Mode = SPI_MODE_MASTER;
  hspi1.Init.Direction = SPI_DIRECTION_2LINES;
  hspi1.Init.DataSize = SPI_DATASIZE_8BIT;
  hspi1.Init.CLKPolarity = SPI_POLARITY_LOW;
  hspi1.Init.CLKPhase = SPI_PHASE_1EDGE;
  hspi1.Init.NSS = SPI_NSS_SOFT;
  hspi1.Init.BaudRatePrescaler = SPI_BAUDRATEPRESCALER_2;
  hspi1.Init.FirstBit = SPI_FIRSTBIT_MSB;
  hspi1.Init.TIMode = SPI_TIMODE_DISABLE;
  hspi1.Init.CRCCalculation = SPI_CRCCALCULATION_DISABLE;
  hspi1.Init.CRCPolynomial = 10;
  if (HAL_SPI_Init(&hspi1) != HAL_OK)
  {
    Error_Handler();
  }
}

/**
  * @brief USART2 Initialization Function
  * @param None
  * @retval None
  */
static void MX_USART2_UART_Init(void)
{

  huart2.Instance = USART2;
  huart2.Init.BaudRate = 115200;
  huart2.Init.WordLength = UART_WORDLENGTH_8B;
  huart2.Init.StopBits = UART_STOPBITS_1;
  huart2.Init.Parity = UART_PARITY_NONE;
  huart2.Init.Mode = UART_MODE_TX_RX;
  huart2.Init.HwFlowCtl = UART_HWCONTROL_NONE;
  huart2.Init.OverSampling = UART_OVERSAMPLING_16;
  if (HAL_UART_Init(&huart2) != HAL_OK)
  {
    Error_Handler();
  }
}

/**
  * @brief GPIO Initialization Function
  * @param None
  * @retval None
  */
static void MX_GPIO_Init(void)
{
  /* GPIO Ports Clock Enable */
  __HAL_RCC_GPIOA_CLK_ENABLE();
  __HAL_RCC_GPIOB_CLK_ENABLE();

  /* USER CODE BEGIN MX_GPIO_Init_2 */
  GPIO_InitTypeDef GPIO_InitStruct = {0};
  GPIO_InitStruct.Pin = GPIO_PIN_4;
  GPIO_InitStruct.Mode = GPIO_MODE_OUTPUT_PP;
  GPIO_InitStruct.Pull = GPIO_NOPULL;
  GPIO_InitStruct.Speed = GPIO_SPEED_FREQ_LOW;
  HAL_GPIO_Init(GPIOA, &GPIO_InitStruct);
  HAL_GPIO_WritePin(GPIOA, GPIO_PIN_4, GPIO_PIN_SET);
  /* USER CODE END MX_GPIO_Init_2 */
}

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


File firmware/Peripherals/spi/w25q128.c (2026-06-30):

#include "w25q128.h"

HAL_StatusTypeDef W25Q128_Init(SPI_HandleTypeDef *hspi){

    uint8_t cmd = W25Q128_REL_POWER_DOWN;
    HAL_GPIO_WritePin(SPI1_CS_GPIO_Port, SPI1_CS_Pin, GPIO_PIN_RESET);
    HAL_SPI_Transmit(hspi, &cmd, 1, 500);
    HAL_GPIO_WritePin(SPI1_CS_GPIO_Port, SPI1_CS_Pin, GPIO_PIN_SET);
    HAL_Delay(1);

    cmd = W25Q128_JEDEC_ID;
    uint8_t id = 0;
    HAL_GPIO_WritePin(SPI1_CS_GPIO_Port, SPI1_CS_Pin, GPIO_PIN_RESET);
    HAL_SPI_Transmit(hspi, &cmd, 1, 500);
    HAL_SPI_Receive(hspi, &id, 1, 500);
    HAL_GPIO_WritePin(SPI1_CS_GPIO_Port, SPI1_CS_Pin, GPIO_PIN_SET);

    if(id != W25Q128_MFR_ID)
        return HAL_ERROR;

    return HAL_OK;
}

HAL_StatusTypeDef W25Q128_Write(SPI_HandleTypeDef *hspi,uint32_t address,uint8_t *data,uint16_t size){
    
    if(W25Q128_WaitBusy(hspi) != HAL_OK) return HAL_ERROR;
    uint8_t cmd = W25Q128_WRITE_ENB;
    HAL_GPIO_WritePin(SPI1_CS_GPIO_Port, SPI1_CS_Pin, GPIO_PIN_RESET);
    HAL_SPI_Transmit(hspi, &cmd, 1, 500);
    HAL_GPIO_WritePin(SPI1_CS_GPIO_Port, SPI1_CS_Pin, GPIO_PIN_SET);
    uint8_t meta[4]={
        W25Q128_PAGE_PROGRAM,
        (address >> 16) & 0xFF,
        (address >> 8) & 0xFF,
        address & 0xFF,
    };
    HAL_GPIO_WritePin(SPI1_CS_GPIO_Port, SPI1_CS_Pin, GPIO_PIN_RESET);
    HAL_SPI_Transmit(hspi, meta, 4, 500);
    HAL_SPI_Transmit(hspi, data, size, 500);
    HAL_GPIO_WritePin(SPI1_CS_GPIO_Port, SPI1_CS_Pin, GPIO_PIN_SET);
    return W25Q128_WaitBusy(hspi);
}

HAL_StatusTypeDef W25Q128_Read(SPI_HandleTypeDef *hspi, uint32_t address, uint8_t *data, uint16_t size){
    if(W25Q128_WaitBusy(hspi) != HAL_OK) return HAL_ERROR;
    uint8_t meta[4]={
        W25Q128_READ_DATA,
        (address >> 16) & 0xFF,
        (address >> 8) & 0xFF,
        address & 0xFF,
    };
    HAL_GPIO_WritePin(SPI1_CS_GPIO_Port, SPI1_CS_Pin, GPIO_PIN_RESET);
    HAL_SPI_Transmit(hspi, meta, 4, 500);
     HAL_SPI_Receive(hspi, data, size, 500);
    HAL_GPIO_WritePin(SPI1_CS_GPIO_Port, SPI1_CS_Pin, GPIO_PIN_SET);
    return HAL_OK;

}

HAL_StatusTypeDef W25Q128_EraseSector(SPI_HandleTypeDef *hspi, uint32_t address){
    // Transaction 1 - Write Enable
    uint8_t cmd = W25Q128_WRITE_ENB;
    HAL_GPIO_WritePin(SPI1_CS_GPIO_Port, SPI1_CS_Pin, GPIO_PIN_RESET);
    HAL_SPI_Transmit(hspi, &cmd, 1, 500);
    HAL_GPIO_WritePin(SPI1_CS_GPIO_Port, SPI1_CS_Pin, GPIO_PIN_SET);

    // Transaction 2 - Sector Erase + address
    uint8_t erase[4] = {
        W25Q128_SECTOR_ERASE,
        (address >> 16) & 0xFF,
        (address >> 8) & 0xFF,
        address & 0xFF
    };
    HAL_GPIO_WritePin(SPI1_CS_GPIO_Port, SPI1_CS_Pin, GPIO_PIN_RESET);
    HAL_SPI_Transmit(hspi, erase, 4, 500);
    HAL_GPIO_WritePin(SPI1_CS_GPIO_Port, SPI1_CS_Pin, GPIO_PIN_SET);

    // Wait until done
    return W25Q128_WaitBusy(hspi);
}
HAL_StatusTypeDef W25Q128_WaitBusy(SPI_HandleTypeDef *hspi){
    uint32_t start = HAL_GetTick();
    while(1){
        uint8_t cmd = W25Q128_READ_STAT_REG_1;
        uint8_t buffer;
        HAL_GPIO_WritePin(SPI1_CS_GPIO_Port, SPI1_CS_Pin, GPIO_PIN_RESET);
        HAL_SPI_Transmit(hspi, &cmd, 1, 500);
        HAL_SPI_Receive(hspi, &buffer, 1, 500);
        HAL_GPIO_WritePin(SPI1_CS_GPIO_Port, SPI1_CS_Pin, GPIO_PIN_SET);
        if((buffer & 0x01) == 0) return HAL_OK;
        if((HAL_GetTick() - start) > 3000) return HAL_TIMEOUT;
    }
}

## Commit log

2026-04-30 chore: initialize project structure with driver and peripheral directories
2026-05-06 feat: implement MPU6050 driver
2026-05-07 feat: add SSD1306 driver skeleton
2026-05-09 feat: complete W25Q128 SPI driver
2026-06-29 fix: resolve build errors and bugs across firmware
    - Complete Makefile with MCU flags, sources, includes, and build targets
    - Fix mpu6050.c: wrong include filename (MPU6050_H -> mpu6050.h)
    - Fix ssd1306.c: missing semicolon on font array, const qualifier on SSD1306_SendData, buffer overflow in SSD1306_Clear
    - Fix ssd1306.h: const qualifier on SSD1306_SendData declaration
    - Fix w25q128.h: replace placeholder GPIO_PIN_x/GPIOx with PA4 (GPIOA, GPIO_PIN_4)
    - Add peripheral init calls in main.c
    [main.c, mpu6050.c]
2026-06-29 Add Makefile and LED blink test
2026-06-29 fix: bug fixes across peripherals and restore SPI1
    - ssd1306: add horizontal addressing mode to SSD1306_Init
    - ssd1306: add size guard (>128) to SSD1306_SendData
    - w25q128: add 3s timeout to W25Q128_WaitBusy
    - w25q128: wait busy after page program in W25Q128_Write
    - main: restore MX_SPI1_Init, comment out temporary LED test code
    [main.c, w25q128.c]
2026-06-30 fix: harden peripheral drivers and fix SPI1 NSS mode
    - Guard MPU6050 ReadAccel/ReadGYRO against uninitialized buffer reads on I2C failure
    - Fix SSD1306_WriteString signature to const char * (header + impl)
    - Switch SPI1 NSS from HARD_OUTPUT to SOFT for W25Q128 CS control
    - Update README changelog with all 2026-06-29 fixes
    [main.c, mpu6050.c]
2026-06-30 feat: add UART peripheral driver (uart.h / uart.c)
    Implements UART_Transmit, UART_TransmitString, and UART_Receive
    wrappers over HAL_UART for use with USART2 (huart2, 115200 baud).
2026-06-30 refactor: inline UART_Transmit calls and remove uart driver
    Replace UART_Print wrapper with direct HAL_UART_Transmit calls in main.c.
    Delete uart.h and uart.c, remove from Makefile sources and includes.
    [main.c]
2026-06-30 feat: verify W25Q128 identity via JEDEC ID in Init
    W25Q128_Init now sends the JEDEC ID command (0x9F), reads the 3-byte
    response, and returns HAL_ERROR if it doesn't match 0xEF/0x40/0x18.
    [w25q128.c]
2026-06-30 fix: only check manufacturer ID byte in W25Q128_Init
    Read and compare only id[0] (0xEF) from the JEDEC response.
    Drop unused MEM_TYPE and CAPACITY defines.
    [w25q128.c]
2026-07-08 docs: add pre-Altium design phase walkthrough to README changelog
    Documents all schematic decisions worked through before entering Altium:
    I2C trace width reasoning, bus capacitance analysis, pull-up resistor
    derivation, SPI mode selection, and STM32 support circuitry values —
    each derived from first principles or verified against datasheets.
2026-07-08 chore: scaffold hardware/ directory and update gitignore for Altium
    Adds hardware/project/ for Altium project files (.PrjPcb, .SchDoc,
    .PcbDoc), hardware/libraries/schematic/ and hardware/libraries/footprints/
    for custom .SchLib/.PcbLib parts files, and hardware/output/ (gitignored)
    for generated Gerbers/BOM. Updates .gitignore to ignore Altium
    auto-generated folders, compiled .IntLib binaries, and report files
    while tracking source library and design files.
2026-07-22 Add Altium hardware design (Revision 1, manufacturing-ready)
    Import the STM32F446-based IMU sensor node PCB project from Altium into
    hardware/. Revision 1 is design-complete: ERC/DRC clean, Gerbers/BOM/CPL
    generated and reviewed for JLCPCB assembly (not yet fabricated or tested).
    - hardware/project/: PrjPcb, PcbDoc (IMU_sensor_node_hardware), Periferals
    and Support schematics, BomDoc, OutJob, and PDF printout.
    - hardware/libraries/schematic/: custom 2.2nF cap symbol.
    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
    [IMU sensor node hardware.PrjPcb, IMU_sensor_node_hardware.PcbDoc, Periferals.SchDoc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]
2026-07-22 Rewrite README and restructure hardware for public presentation
    Reframe the project as "STM32 Multi-Protocol IMU Data Logger" and publish the
    custom PCB work honestly, per external review.
    README:
    - New title + one-sentence pitch + honest Rev 1 status (design complete;
    ERC/DRC passed; Gerber/BOM/CPL reviewed; fabrication and bring-up pending).
    - Add system architecture (mermaid), "what I personally designed", firmware
    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
    [IMU sensor node hardware.PrjPcb, IMU_sensor_node_hardware.PcbDoc, Periferals.SchDoc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]
2026-07-22 Fix documentation accuracy for recruiter-ready branch
    Address review findings without touching the reviewed Gerber/BOM/CPL or the
    Altium binary sources.
    - Board preview: the exports PNG is a screenshot of the CPL spreadsheet, not a
    PCB render. Renamed pcb-placement-preview.png -> cpl-table-screenshot.png and
    removed it from the README hero; state real PCB renders are pending.
    - License: add a real MIT LICENSE (Copyright (c) 2026 Ayrathan Jegasothy) and
    link it from the README.
    - Power section: correct to match the released BOM — AMS1117 uses 4.7 uF
    ceramic input (C17) and 22 uF tantalum output (C18), not 22 uF for both.
    - Authorship: split claims into original design work, hand-bu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
2026-07-22 Add top-side 3D board render to hardware exports
    Add the Altium 3D render of the Revision 1 board (top side, provided from
    Altium) as hardware/exports/pcb-top.png and use it as the README hero image,
    replacing the "renders pending" placeholder. Bottom-side render and a clean
    schematic-only PDF remain the outstanding Altium exports.
2026-07-22 Frame as hardware/firmware-architecture prototype and polish README
    - Reframe the intro and status: state plainly that the PCB is manufacturing-
    ready and drivers are written, but the board is untested and the end-to-end
    data-logging loop is not implemented — this is a PCB + firmware-architecture
    prototype, not a validated running data logger.
    - Move the "silkscreen designators still in cleanup" note out of the hero-image
    caption and into Known limitations.
    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
2026-07-22 Add SSD1306_SetCursor and wire up accel/gyro read+format loop
2026-07-24 Complete data-logging loop: OLED display, UART telemetry, flash logging with sector wraparound
2026-07-24 docs: README reflects clean build + Nucleo bring-up (loop/UART/error paths confirmed)

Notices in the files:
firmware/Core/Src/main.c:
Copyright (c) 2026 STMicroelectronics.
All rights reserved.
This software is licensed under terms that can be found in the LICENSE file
